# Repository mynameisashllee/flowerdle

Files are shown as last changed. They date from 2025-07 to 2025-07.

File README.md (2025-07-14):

# flowerdle
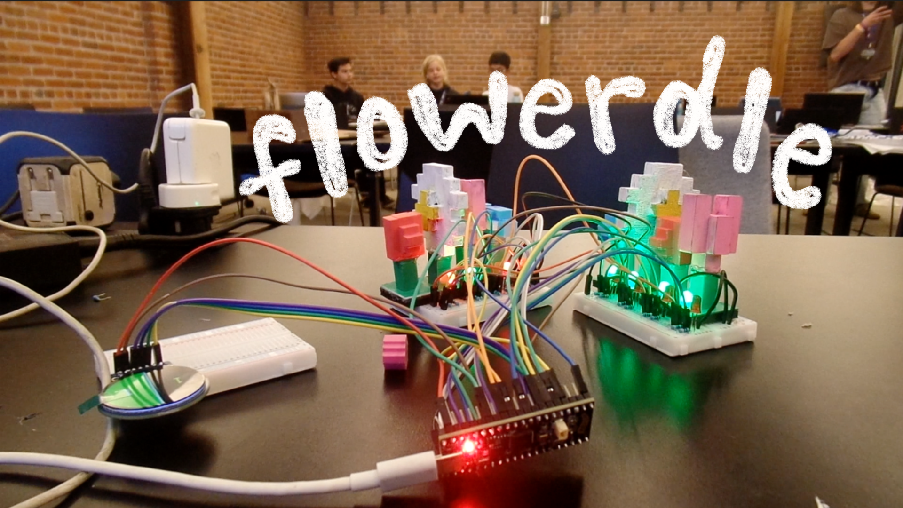
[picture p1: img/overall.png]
overall


## description
flowerdle is a real life two player wordle game - but instead of letters, there's minecraft flowers! and instead of one person, there's two! compete in a fierce race to guess the right flowers... or perish by pollen. just kidding.

## youtube demo
[link](https://youtu.be/ab2HIsHCvx8)

## how it works
there are four flowers - tulips (pink), poppies (red), oxeye daisies (white) and cornflowers (blue). each flower has a resistor of different resistance inside it to distinguish them. the resistors are held below each flower stem with a case, with pins poking out the bottom so you can plant them into the breadboard.
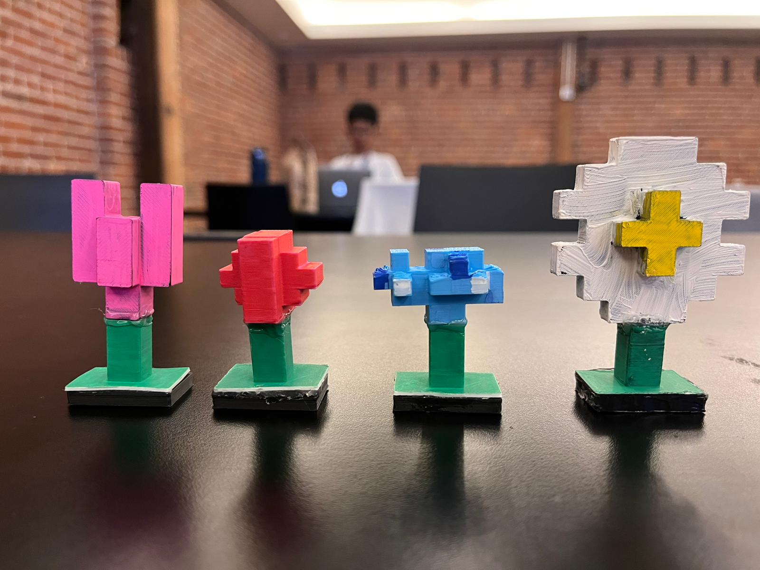
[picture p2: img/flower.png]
flower


at the start, the firmware generates a random four-colour code. the aim for both players is to guess the correct order of the colours in the least amount of tries.

there are 2 breadboards for players with spaces to put the flowers and leds (red and green).
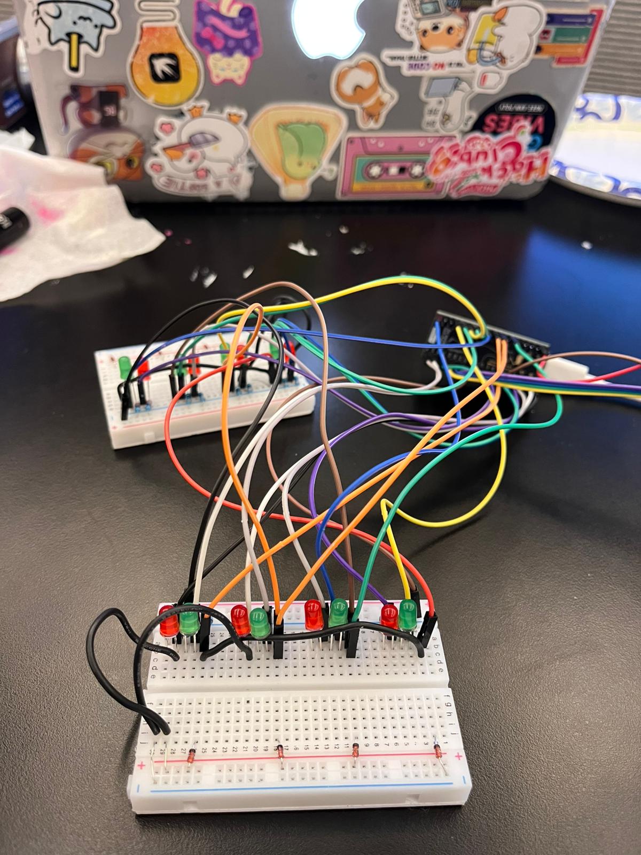
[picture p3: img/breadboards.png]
breadboards


and there's a breadboard for the oled display.
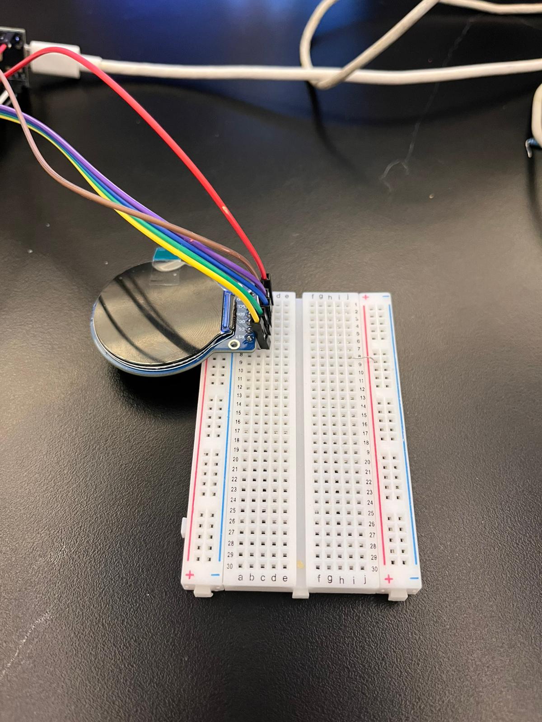
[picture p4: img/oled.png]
oled


the breadboard cases have unfortunately not been printed as of shipping, but hopefully will be before project demos! check out how they will look in the [cad files](src/cad/breadboardcase).

on each turn, you plug in all four flowers for your guess. then, the led lights up green or red based on whether the guess for that slot is correct or wrong, respectively.
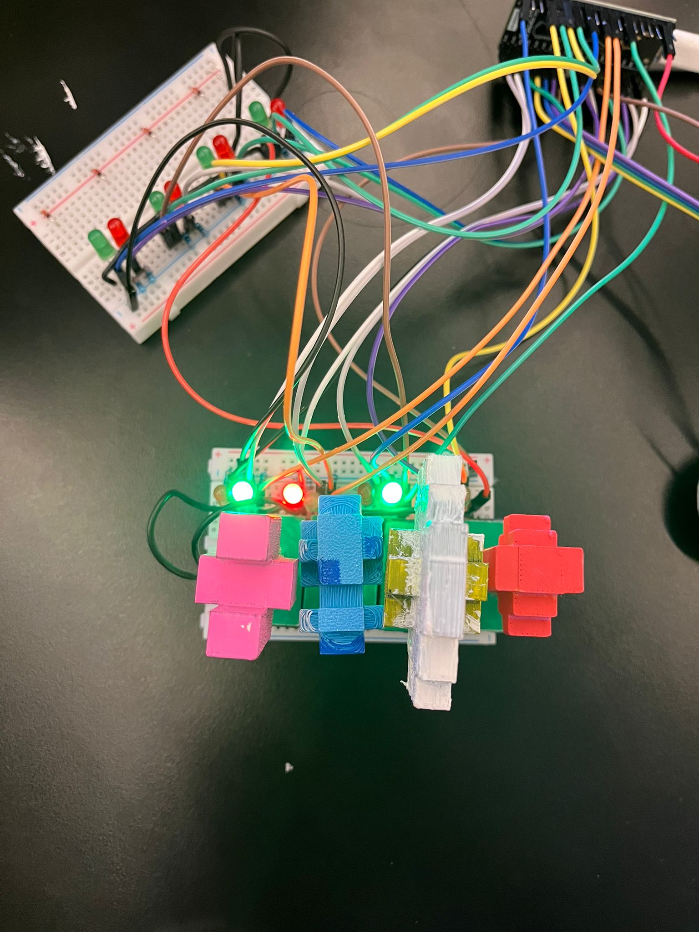
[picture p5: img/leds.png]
leds


once your turn is done, it increments the number of tries on the display. whoever gets the code correct first with the least number of tries wins! 
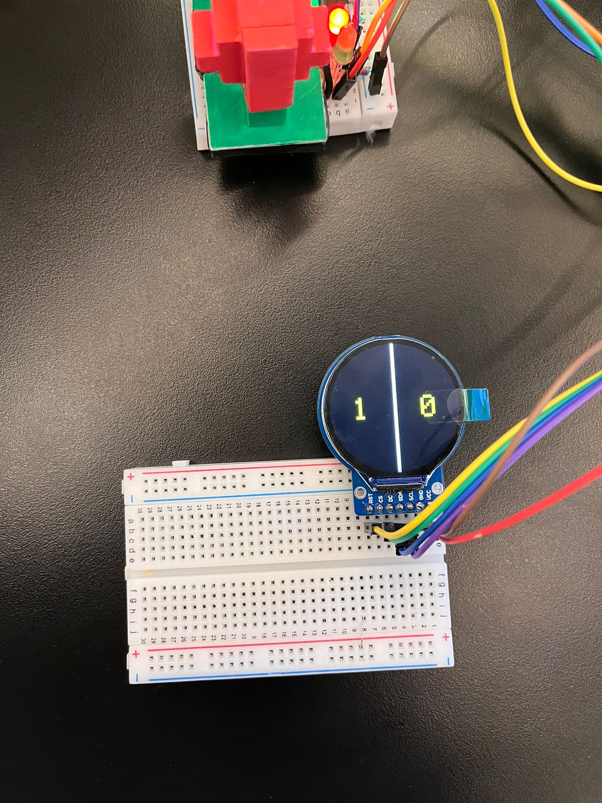
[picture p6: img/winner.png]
winner


## schematic
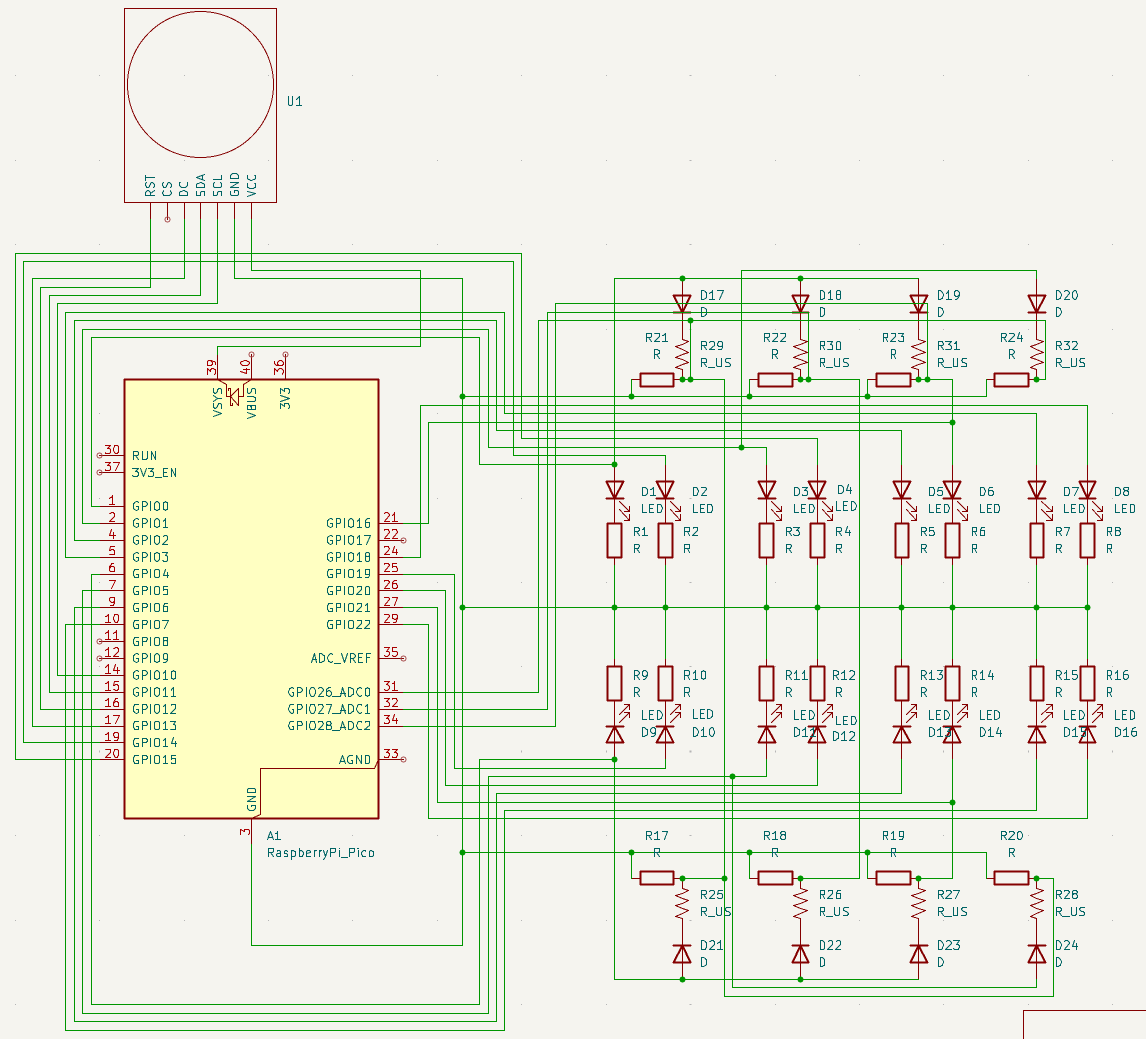
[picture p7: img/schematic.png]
schematic


## journal
take a look at our daily journals at [journals](journal) and our process pictures at [pictures](journal/pics.md) (featuring food pics!).

## building files
* 📂 src
    * [📂 cad](src/cad)
        * [📄 case cads](src/cad/breadboardcase)
        * [📄 flower cads](src/cad/flowers)
        * [📄 flower base cads](src/cad/structures)
    * [📂 firmware](src/firmware)
        * [📄 code.py](src/firmware/code.py)
    * [📂 schematic](src/schematic)
        * 📄 kicad files
    * [📄 bom](src/bom.md)

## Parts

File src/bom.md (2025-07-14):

# BOM
| Item | Amount |
| --- | --- |
| RP2040 | 1 |
| Breadboard | 3 |
| 390 resistor | 16 |
| 1.2k resistor | 8 |
| 2k resistor | 2 |
| 3.4k resistor | 2 |
| 4.2k resistor | 2 |
| 1.28" TFT LCD | 1 |
| LED (Red) | 8 |
| LED (Green) | 8 |
| Diode | 8 |
| Jumper wires (male - female) | 26 |
| Jumper wires (male - male) | 10 |
| Hot glue | lots |
| 3D Print Filament | lots |

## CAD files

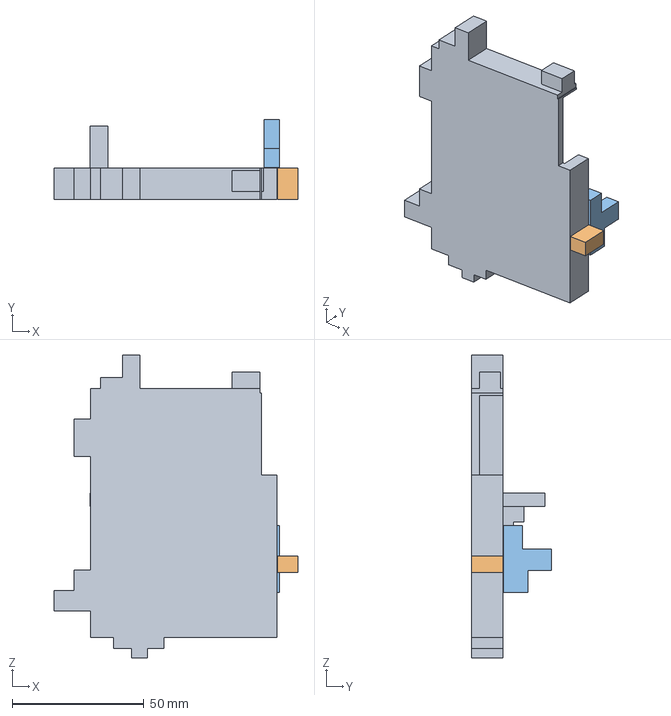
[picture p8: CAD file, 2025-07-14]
src/cad/breadboardcase/with_oled.step
92.5 x 30.5 x 115.0 mm

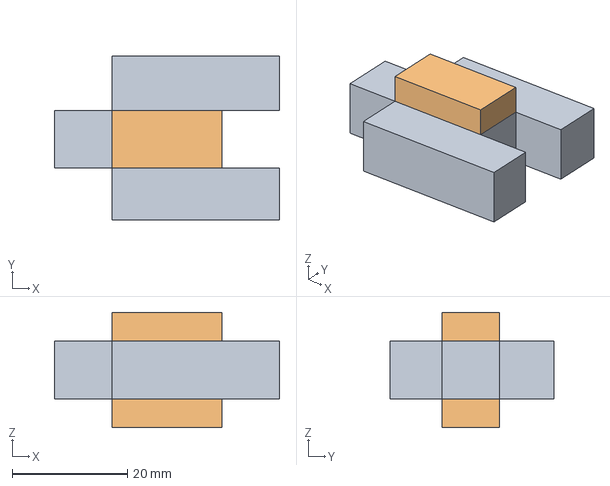
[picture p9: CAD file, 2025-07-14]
src/cad/flowers/pinkflower.step
39.0 x 28.4 x 20.0 mm

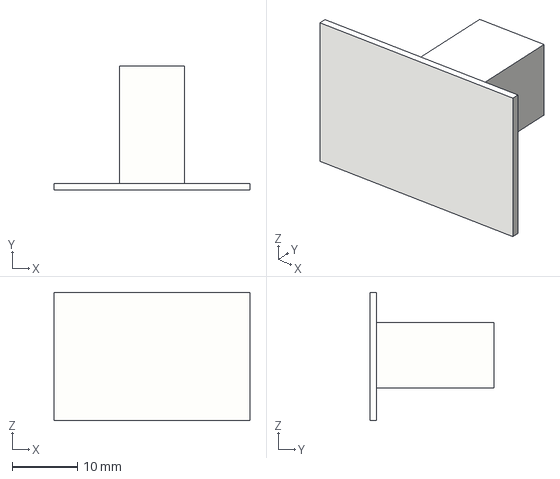
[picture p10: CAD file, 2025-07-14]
src/cad/structures/flowerstem.step
30.0 x 19.0 x 19.6 mm

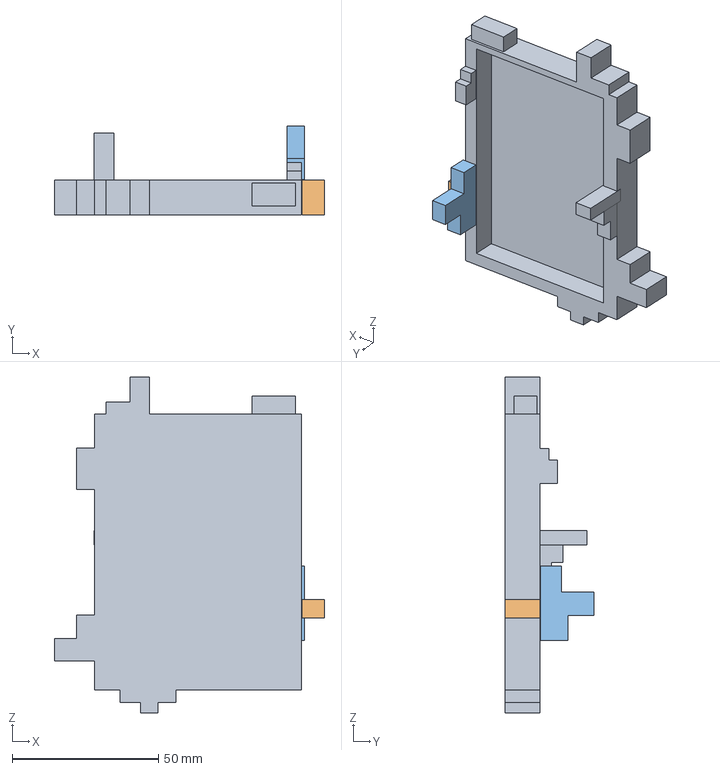
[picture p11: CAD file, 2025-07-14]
src/cad/breadboardcase/no_oled.step
92.5 x 30.5 x 115.0 mm

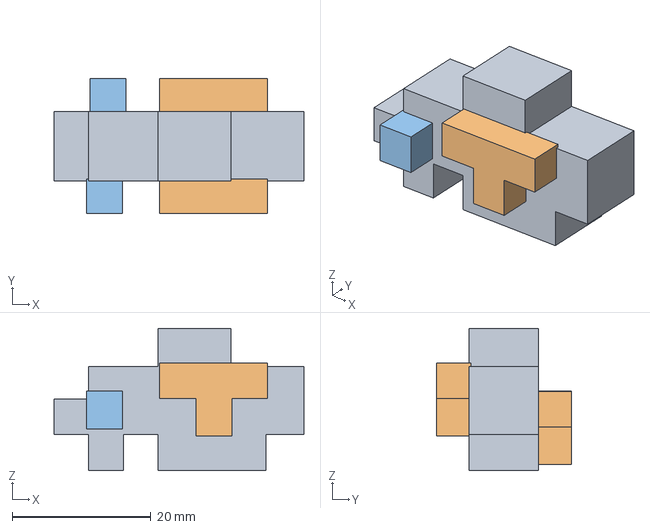
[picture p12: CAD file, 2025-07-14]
src/cad/flowers/blueflower.step
36.0 x 19.5 x 20.5 mm

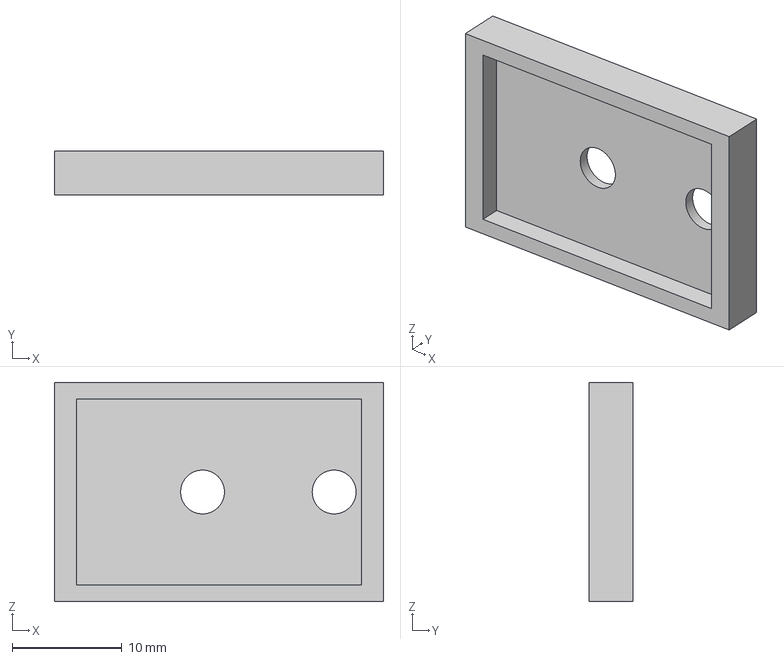
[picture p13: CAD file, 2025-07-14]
src/cad/structures/flowerbase.step
30.0 x 4.00 x 20.0 mm

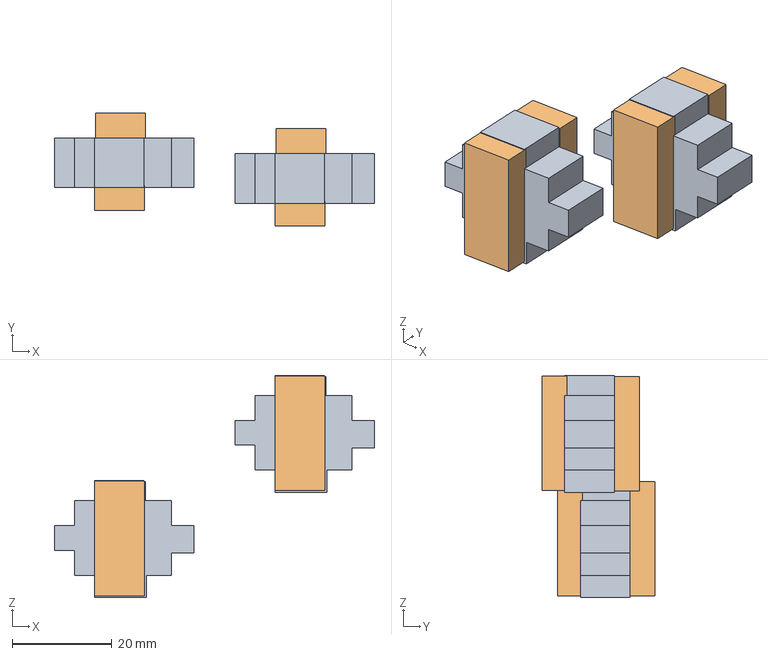
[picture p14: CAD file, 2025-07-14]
src/cad/flowers/redflower.step
64.2 x 22.7 x 44.6 mm

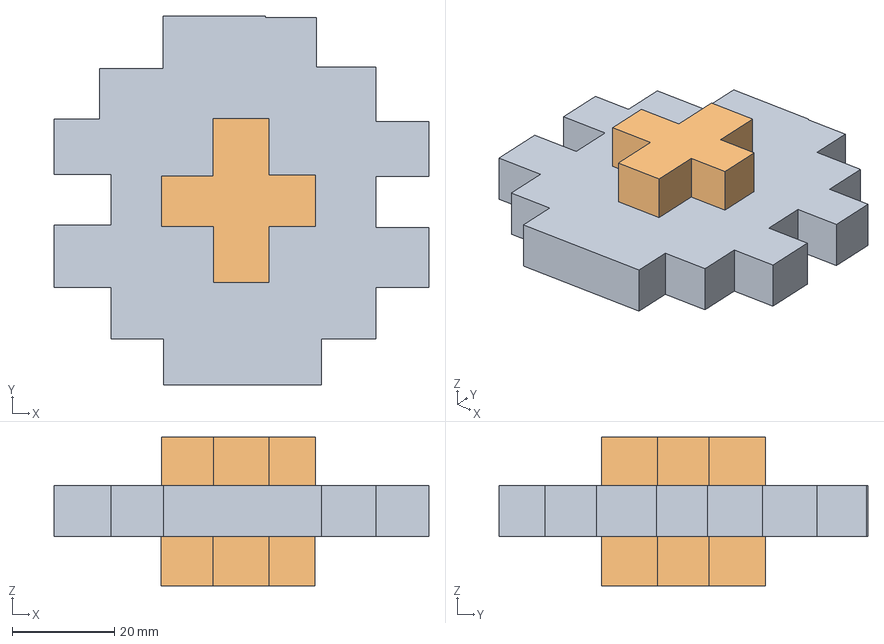
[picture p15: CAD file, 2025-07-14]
src/cad/flowers/whiteflower.step
73.2 x 72.1 x 29.0 mm

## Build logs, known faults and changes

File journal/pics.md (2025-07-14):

# digicam photos!
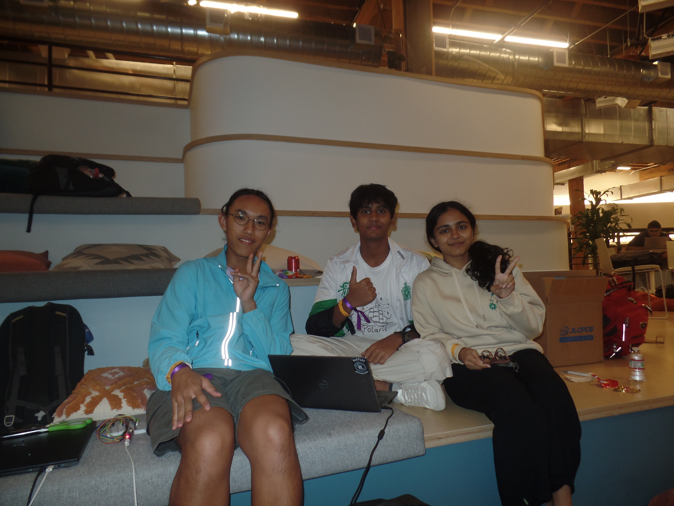
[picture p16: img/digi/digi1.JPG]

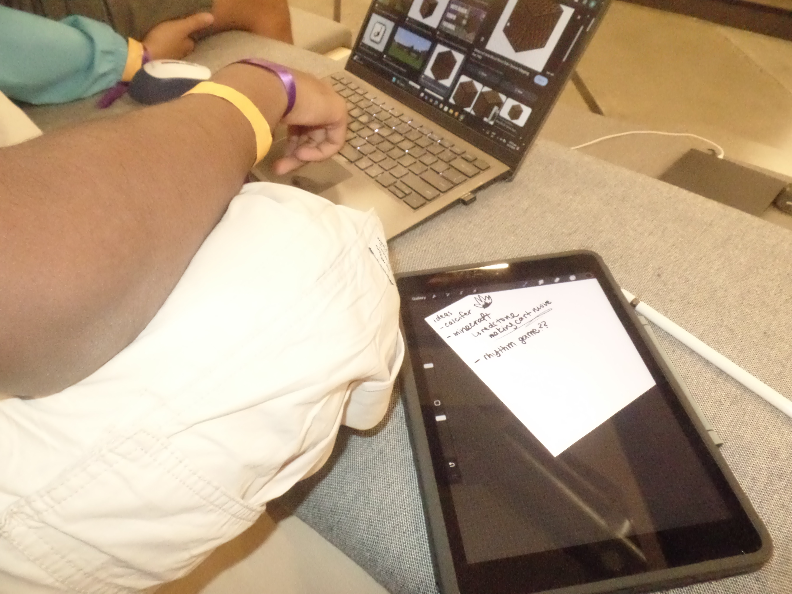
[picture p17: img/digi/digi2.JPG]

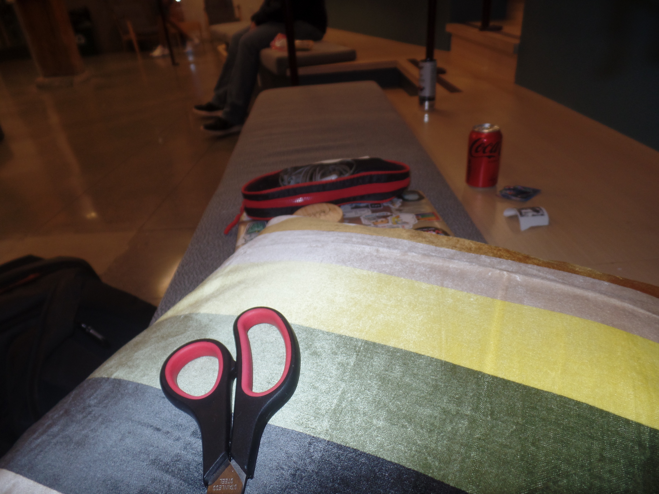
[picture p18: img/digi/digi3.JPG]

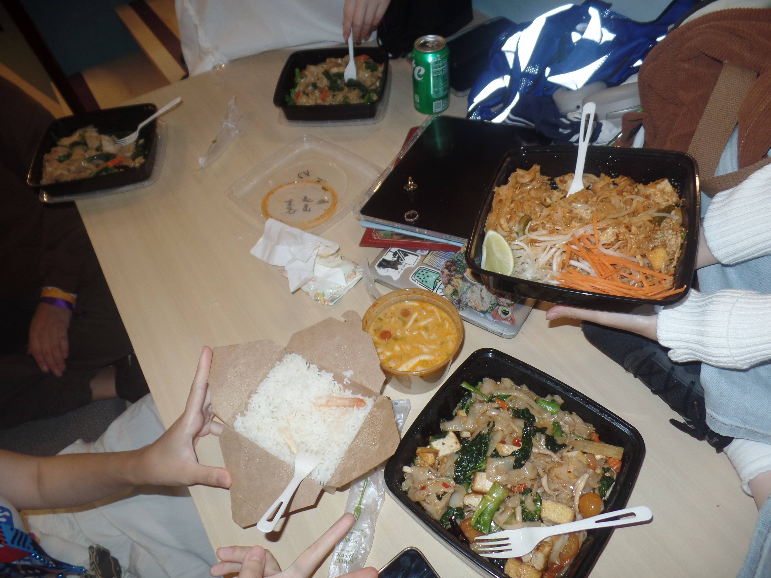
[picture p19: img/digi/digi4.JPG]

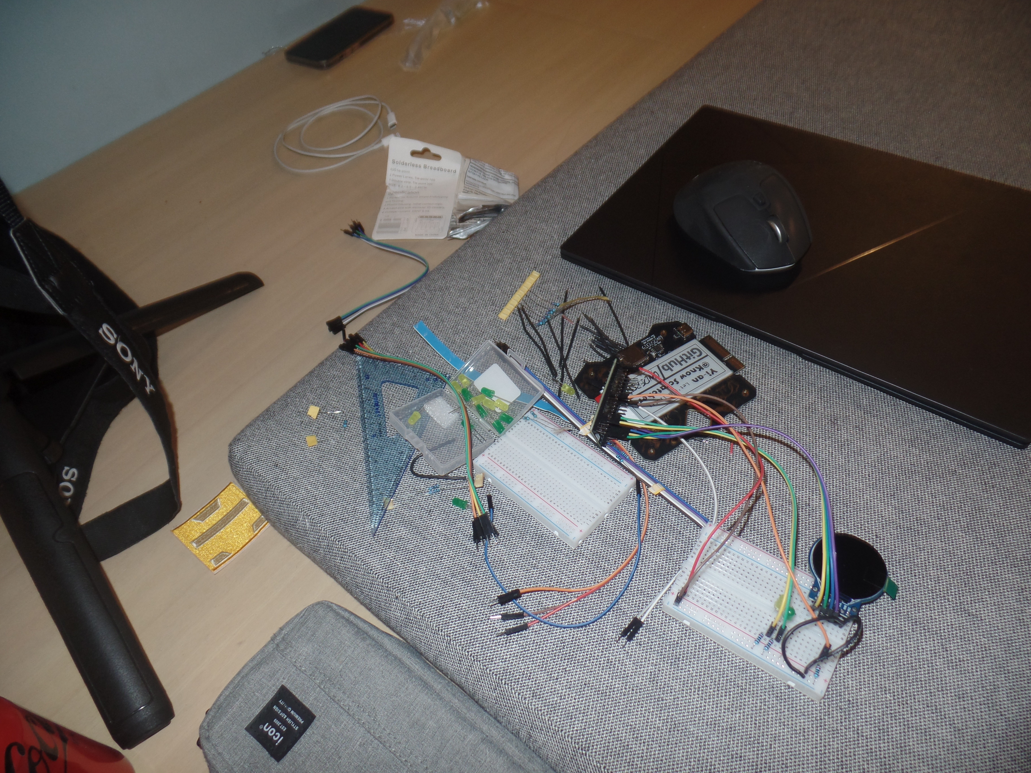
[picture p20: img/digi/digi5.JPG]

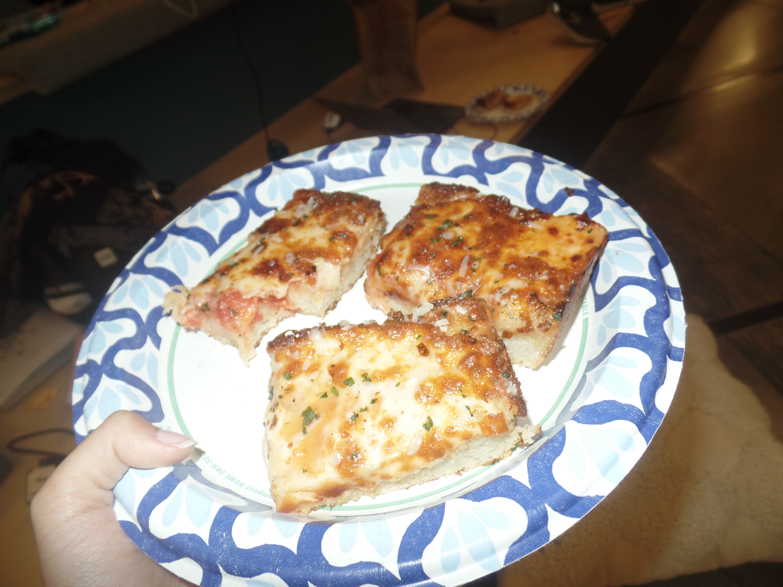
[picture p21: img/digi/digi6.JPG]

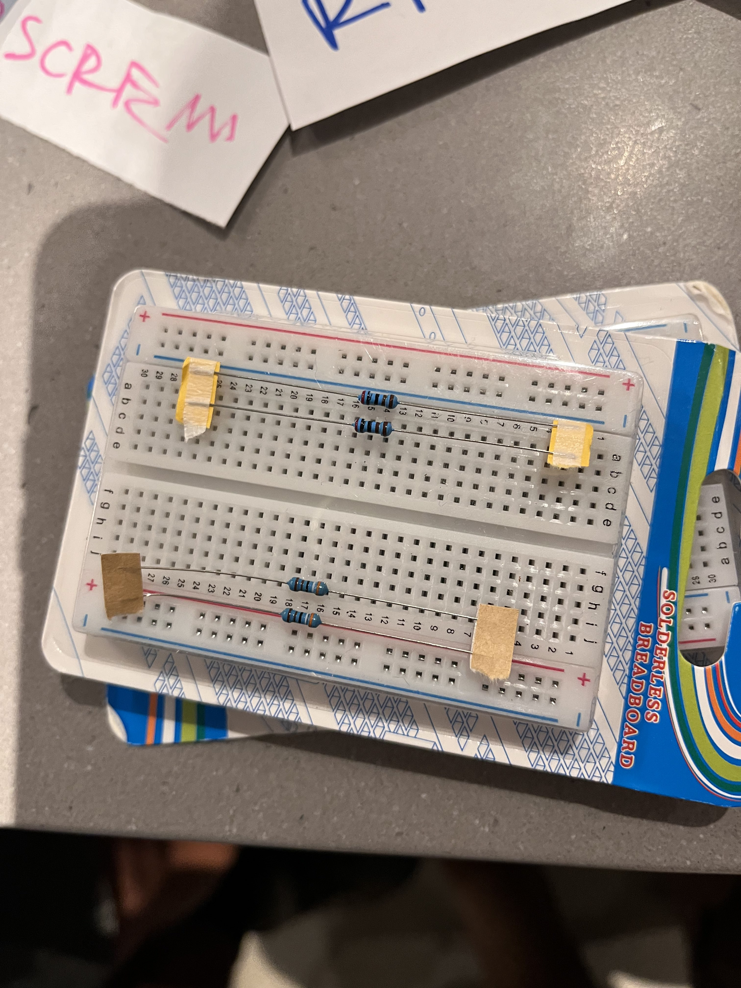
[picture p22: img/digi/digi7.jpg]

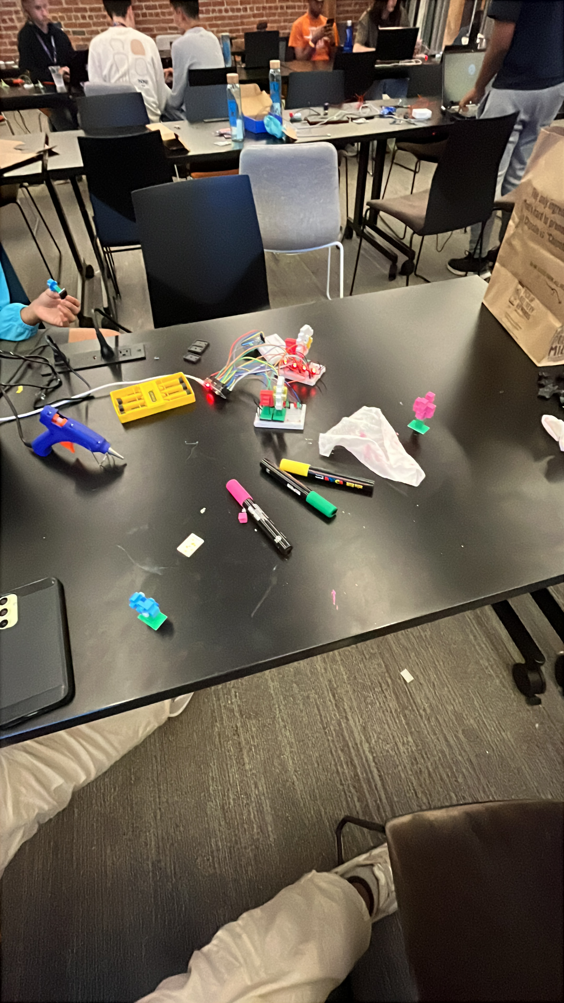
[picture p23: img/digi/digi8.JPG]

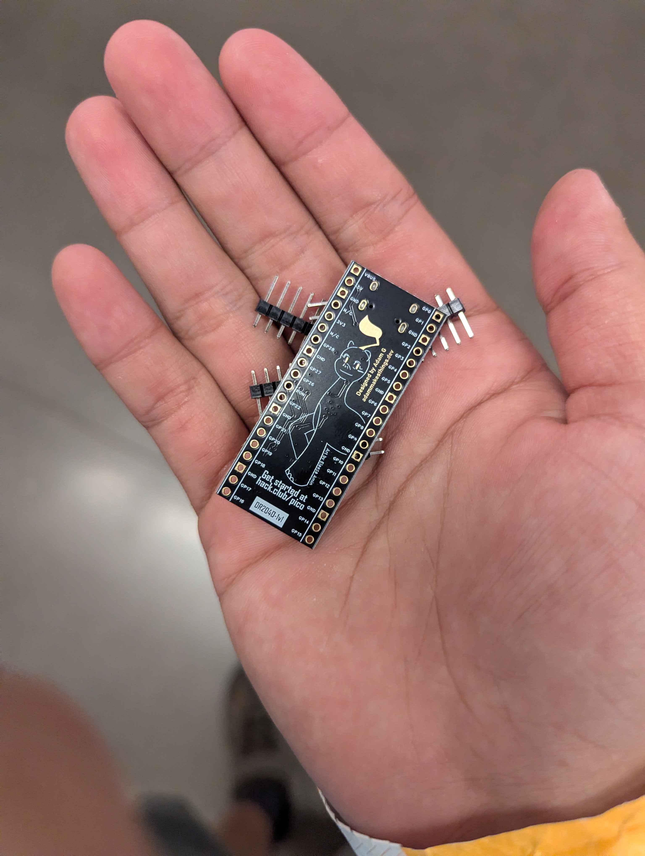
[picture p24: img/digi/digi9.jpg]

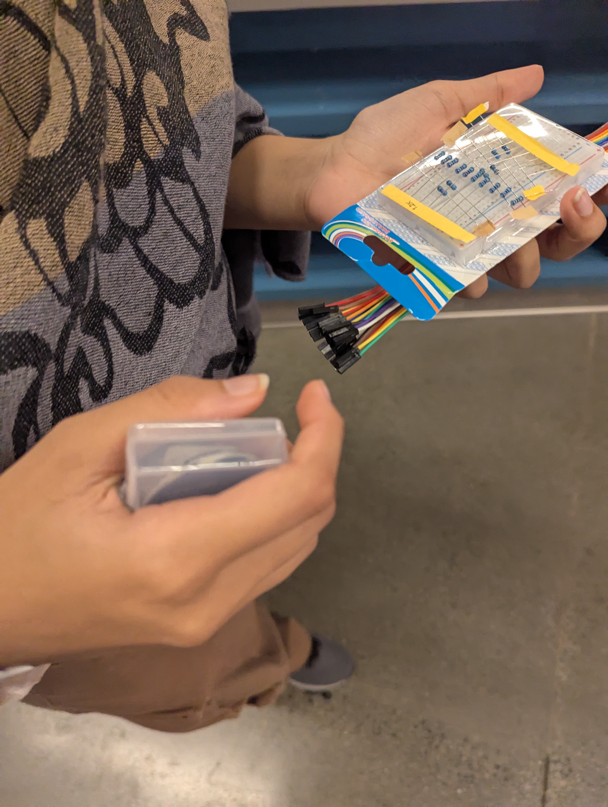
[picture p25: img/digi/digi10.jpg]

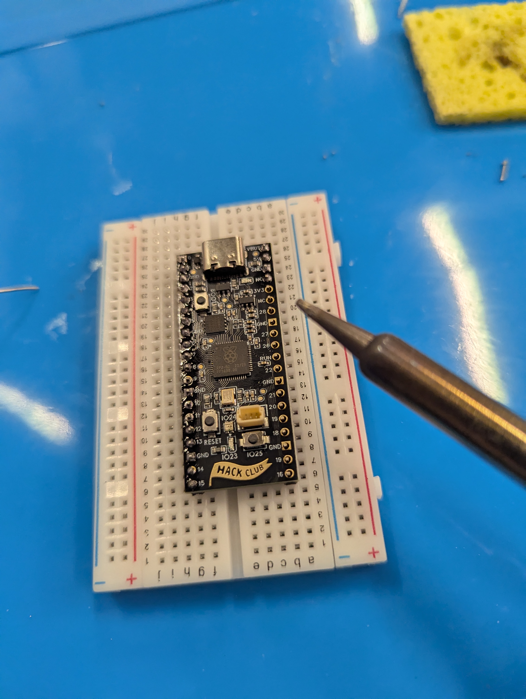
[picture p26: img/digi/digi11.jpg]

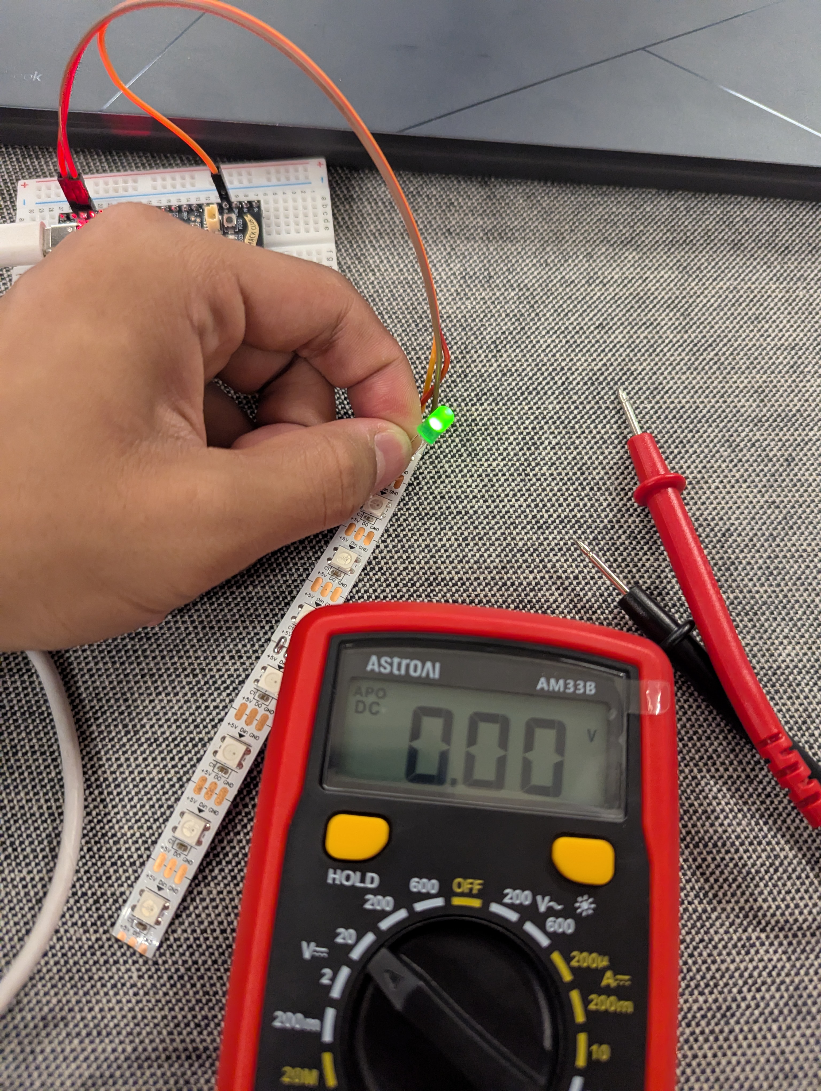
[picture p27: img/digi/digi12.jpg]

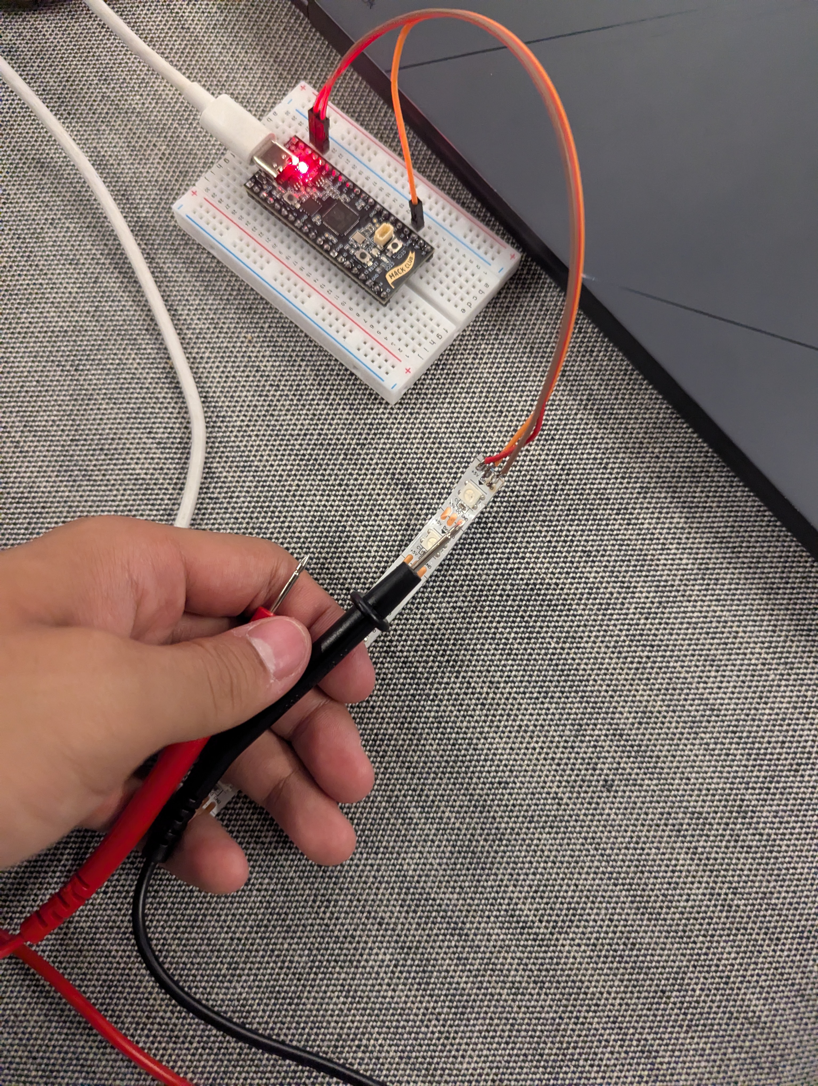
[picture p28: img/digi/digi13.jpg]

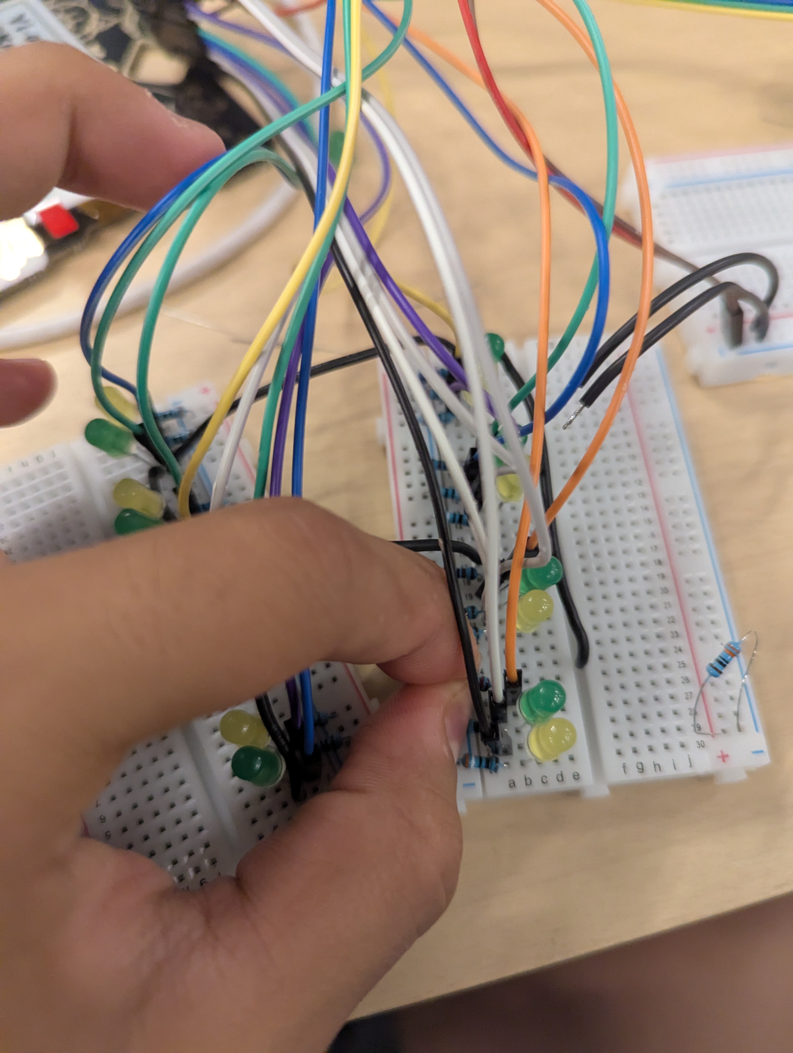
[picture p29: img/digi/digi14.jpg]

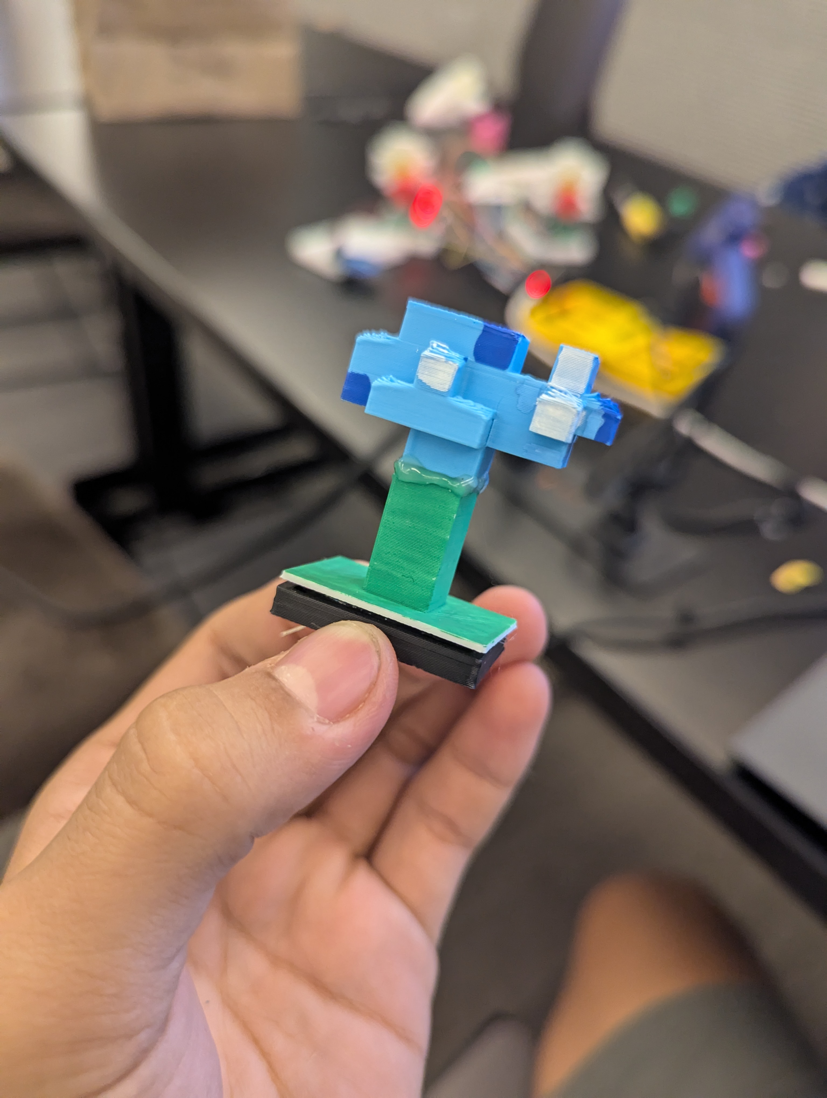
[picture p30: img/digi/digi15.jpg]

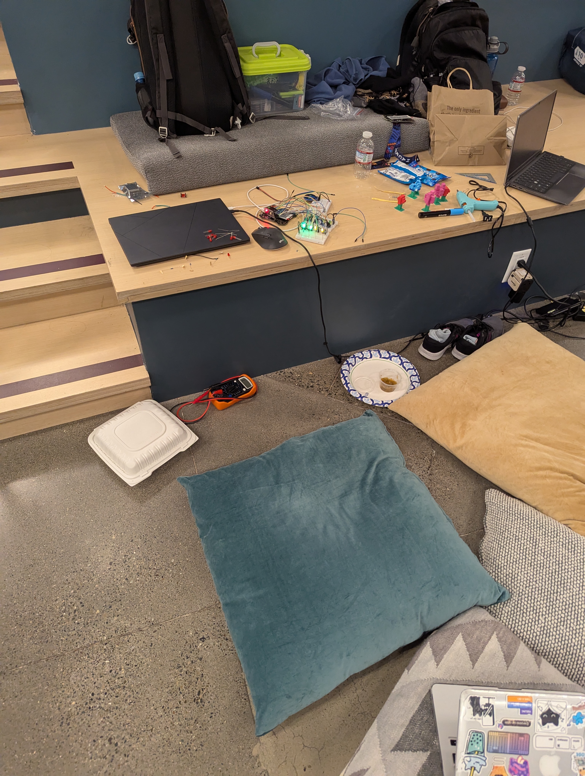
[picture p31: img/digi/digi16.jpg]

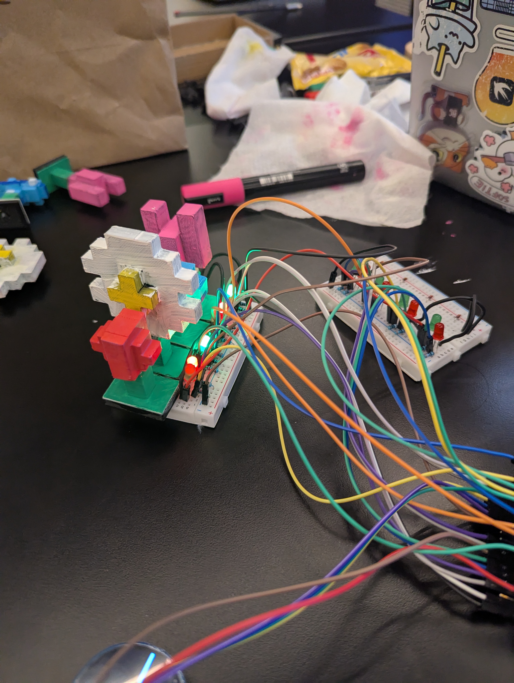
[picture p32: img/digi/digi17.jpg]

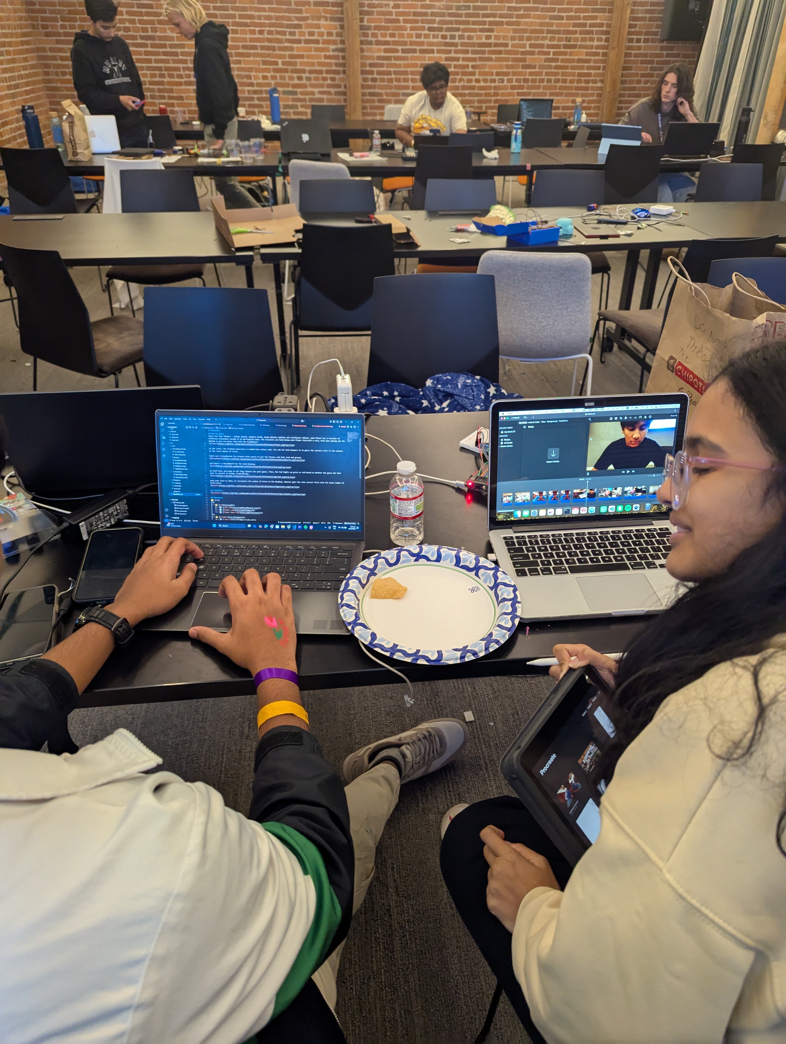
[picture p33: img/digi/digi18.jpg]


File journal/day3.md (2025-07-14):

# day 3 - 13 jul 
Its the last full day to finish our project(#crashingout). Okay but we're on track(kind of), except our 3d prints for two of our flowers aren't here yet. We finished working on the breadboard cases which are minecraft themed as well(grass blocks!!) The queue for the 3d printer is not looking good though but apparently we'll be able to start printing at 7pm and get it by 9!.

We also refined our firmware and got it fully functioning. 

We got our prints at around 9.30 but bad news!! Our prints are all in black(lowkey cooked given our game depends on having different coloured flowers). But the paint markers saved the day and we managed to get some white paint too and we repainted the flowers but we're yet to get out breadboard case which will apparently be ready before 8 am tomorrow.

Also WHY ARE 3D PRINT SUPPORTS SO HARD TO REMOVE?? (might've accidentally injured myself with the tweezers but we're balling!!)

We painted and assembled all our flowers and our electronics and fully tested things out at around 1.20 am after undernet and IT WORKS!!!

Now we just got to work on getting all our files ready to ship(which is all over the place ngl) and we're going to hope that tomorrow's breadboard cases come in time for us to assemble it. 

Might be a long night and we're all hiked up on so much caffiene but what's the fun in a hackathon if you're not up all night doing goofy things while speedrunning right? 

Thats it for day 3, and I should probably lock in now!

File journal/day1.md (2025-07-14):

## day 1 - 11 jul (fri)
for the first day, after settling in, we formed our teams and started brainstorming ideas (after some caffeine)

before settling on our final (floral!) idea, some of our scrapped ideas include:
- calcifer from howl's moving castle
- real life minecraft redstone minecart??
- mini rhythm game (like osu or taiko)

we figured that if we incorporated minecraft flowers into a codebreaker-style game, we retained a sense of whimsy while also making it more interactive. then, we got the idea to add two players for extra competition and fun (!!!)

basically, the firmware generates a random code of four colours which the players have to guess the sequence of by slotting minecraft flowers of the respective colours into four sockets. then, leds below the sockets tell you whether the flower is correct or wrong by lighting up red or green. to distinguish the different types of flowers, we are using resistors of varying resistance to complete the circuit. (we tried going through potential ideas for this like a photoresistor or distance sensors, but this was the most viable way)

by the time we figured out the circuit and went to collect our hardware, it was 2am. we discovered and soldered an orpheus pico and found this really fun round oled screen (thanks joe). we also got very many resistors which are really hard to distinguish in low light and while sleep deprived.

at about 2.40am, we tried to clear up the mess and created the repo. sadly, we realised that we had forgotten to get the leds and resistors and include them in the wiring ): job for tomorrow. goodnight!

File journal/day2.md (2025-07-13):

# day 2 - 12 jul (sat)
today, we woke up super early and split up tasks.

we did some cad and 3d printed the flowers! we decided on four colours according to the filament - dandelion for yellow, tulip for pink, cornflower for blue and rose for red. For the tulips, we printed out individual blocks and glued them together because it didnt need too many but for the rest we just patterned them in cad instead of assembling it to save on time. 
the bottom plate needed some adjustment because the resistor holes didn't print right, and the size was kind of off. so i guess that's a problem for tomorrow. 
Had 2 project demos today which went quite well, and we went through our 3d designs that were printed out as well as our firmware.
Turns out the other two were printed in the wrong colour and our adjusted bottom plate is yet to be printed so those two are a problem for tomorrow i guess
Right now we're relying on paint markers to fix the colour problems in case too many people need the 3d printers tomorrow
and thats it for the night. goodnight!

or probably not so fast, cus I just stayed up and try to get the firmware done.

It was a pretty serious problem: the pins are not enough.
So I go google for some details and found something worse: not only the GPIO pin are not enough, bout we only have 3 analog pins to read 4 analog data.
I searched online to see if I can find any solution. I also talked to Gemini. But after all, I decide I .have to share the pins.

This is basically how it's going to work.
First, I can use a main GPIO pin to provide power for the sensor, and then just read the values and cut it off and switch to the secondary GPIO pin and read the remaining value, and finally switch back to the original state.

I worked like till 4 am. so hope I can still lock in tomorrow. (PS I'm having too much caffeine I'm just want to sleep now.)

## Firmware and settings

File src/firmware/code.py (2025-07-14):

import board
import digitalio
import analogio
import time
import os
import random
import math
import busio
import terminalio
import displayio
from adafruit_display_text import label
import gc9a01 # type: ignore
from vectorio import Rectangle

# Release any resources currently in use for the displays
displayio.release_displays()

# Raspberry Pi Pico pinout, one possibility, at "southwest" of board
tft_clk = board.GP10 # must be a SPI CLK
tft_mosi= board.GP11 # must be a SPI TX
tft_rst = board.GP12
tft_dc  = board.GP13
tft_cs  = None
tft_bl  = None
spi = busio.SPI(clock=tft_clk, MOSI=tft_mosi)

display_bus = displayio.FourWire(spi, command=tft_dc, chip_select=tft_cs, reset=tft_rst) # type: ignore
display = gc9a01.GC9A01(display_bus, width=240, height=240, backlight_pin=tft_bl)

# Make the main display context
main = displayio.Group()
display.root_group = main



# Draw a text label
palette = displayio.Palette(1)
palette[0] = 0xffffff
bar_group = displayio.Group(scale=2)
bar = Rectangle(pixel_shader=palette, x=60, y=0, width=5, height=240)
bar_group.append(bar)
main.append(bar_group)
p1_status = displayio.Group(scale=2)
p2_status = displayio.Group(scale=2)
palette_win = displayio.Palette(1)
palette_win[0] = 0x00ff00
palette_lose = displayio.Palette(1)
palette_lose[0] = 0xff0000
p1_color = Rectangle(pixel_shader=palette_win, x=0, y=0, width=120, height=240)
p2_color = Rectangle(pixel_shader=palette_win, x=60, y=0, width=120, height=240)
p1_status.append(p1_color)
p2_status.append(p2_color)

p1_count, p2_count = 0, 0
p1_text = str(p1_count)
p1_text_area = label.Label(terminalio.FONT, text=p1_text, color=0xFFFF00,
                        anchor_point=(3.5,3.5), anchored_position=(30,60))
p1_text_group = displayio.Group(scale=5)
p1_text_group.append(p1_text_area) 
main.append(p1_text_group)

p2_text = str(p2_count)
p2_text_area = label.Label(terminalio.FONT, text=p2_text, color=0xFFFF00,
                        anchor_point=(3.5,3.5), anchored_position=(55,60))
p2_text_group = displayio.Group(scale=5)
p2_text_group.append(p2_text_area) 
main.append(p2_text_group)

wrong_pins = [board.GP0, board.GP1, board.GP2, board.GP3, board.GP4, board.GP5, board.GP6, board.GP7]
right_pins = [board.GP14, board.GP15, board.GP16, board.GP18, board.GP19, board.GP20, board.GP21, board.GP22]
analog_pins = [board.GP26, board.GP27, board.GP28]

wrongs: list[digitalio.DigitalInOut] = []
rights: list[digitalio.DigitalInOut] = []
analog: list[analogio.AnalogIn] = []
for i in wrong_pins:
    wrongs.append(digitalio.DigitalInOut(i))
    wrongs[-1].direction = digitalio.Direction.OUTPUT
for i in right_pins:
    rights.append(digitalio.DigitalInOut(i))
    rights[-1].direction = digitalio.Direction.OUTPUT
for i in analog_pins:
    analog.append(analogio.AnalogIn(i))

# mp = {
#     48: 0,
#     47: 0,
#     46: 0,
#     36: 1,
#     35: 1,
#     34: 1,
#     23: 2,
#     22: 2,
#     21: 2,
#     13: 3,
#     12: 3,
#     11: 3
# }
# mp = {
#     32: 0,
#     31: 0,
#     30: 0,
#     24: 1,
#     23: 1,
#     22: 1,
#     16: 2,
#     15: 2,
#     14: 2,
#     9: 3,
#     8: 3,
#     7: 3
# }
mp = {
    31: 0,
    30: 0,
    29: 0, 
    20: 1,
    19: 1,
    18: 1,
    13: 2,
    12: 2,
    11: 2,
    7: 3,
    6: 3,
    5: 3
}
# v4
# 820 = 30***
# 2k   = 19***
# 3.4k = 12***
# 4.2k = 6***

def read(sw1:  digitalio.DigitalInOut, sw2:  digitalio.DigitalInOut, sw3:  digitalio.DigitalInOut, sw4:  digitalio.DigitalInOut):
    tmp1, tmp2, tmp3, tmp4 = sw1.value, sw2.value, sw3.value, sw4.value
    p1, p2 = [], []
    sw1.value, sw2.value, sw3.value, sw4.value = True, False, False, False # p1 main
    p1.append(analog[0].value)
    p1.append(analog[1].value)
    p1.append(analog[2].value)
    sw1.value, sw2.value, sw3.value, sw4.value = False, True, False, False # p1 sub
    p1.append(analog[0].value)
    sw1.value, sw2.value, sw3.value, sw4.value = False, False, True, False # p2 main
    p2.append(analog[0].value)
    p2.append(analog[1].value)
    p2.append(analog[2].value)
    sw1.value, sw2.value, sw3.value, sw4.value = False, False, False, True # p2 sub
    p2.append(analog[0].value)
    sw1.value, sw2.value, sw3.value, sw4.value = tmp1, tmp2, tmp3, tmp4
    return p1, p2

    

nums = [0, 1, 2, 3]
ans = []
seed_bytes = os.urandom(4)
seed_int = int.from_bytes(seed_bytes, 'big')
random.seed(seed_int)
for i in range(4):
    index = random.randint(0, len(nums) - 1)
    ans.append(nums[i % len(nums)])
    nums.pop(i % len(nums))
print(ans)

p1_lock, p2_lock = False, False
while True:
    p1, p2 = read(wrongs[0], wrongs[1], wrongs[4], wrongs[5])
    print(p1, p2)
    if all([x // 1000 > 0 for x in p1]):
        if not p1_lock and p1_count >= 0:
            p1_lock = True
            p1_count += 1
            p1_text_area.text = str(p1_count)
            for i in range(4):
                wrongs[i].value = not(mp.get(p1[i] // 1000, ans[i]) == ans[i])
                rights[i].value = mp.get(p1[i] // 1000, -1) == ans[i]
            if all(mp.get(p1[i] // 1000, -1) == ans[i] for i in range(4)):
                main.insert(0, p1_status)
                p1_text_area.color = 0xffffff
                p1_count = -1
    else: #if all([x // 1000 < 0 for x in p1]) and p1_lock:
        for i in range(4):
            wrongs[i].value = False
            rights[i].value = False
        p1_lock = False

    if all([x // 1000 > 0 for x in p2]):
        if not p2_lock and p2_count >= 0:
            p2_lock = True
            p2_count += 1
            p2_text_area.text = str(p2_count)
            for i in range(4):
                wrongs[i + 4].value = not(mp.get(p2[i] // 1000, ans[i]) == ans[i])
                rights[i + 4].value = mp.get(p2[i] // 1000, -1) == ans[i]
            if all(mp.get(p2[i] // 1000, -1) == ans[i]for i in range(4)):
                main.insert(0, p2_status)
                p2_text_area.color = 0xffffff
                p2_count = -1
    else: #if all([x // 1000 < 0 for x in p2]) and p2_lock:
        for i in range(4):
            wrongs[i + 4].value = False
            rights[i + 4].value = False
        p2_lock = False
    time.sleep(0.5)
# v1
# 1.2k = 47***
# 2k   = 35***
# 3.4k = 22***
# 4.2k = 12***

# v2
# 1.2k = 31***
# 2k   = 23***
# 3.4k = 15***
# 4.2k = 8***

# v3
# 1.2k = 25***
# 2k   = 19***
# 3.4k = 12***
# 4.2k = 6***

# v4
# 820 = 30***
# 2k   = 19***
# 3.4k = 12***
# 4.2k = 6***

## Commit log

2025-07-12 update BOM
2025-07-14 update BOM, update firmware
2025-07-14 organised and edited readme
    [blueflower.step, flowerbase.step, flowerstem.step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]
2025-07-14 update sch
    [flowerdle.kicad_sch]
2025-07-14 update pics n links
    [no_oled.step, with_oled.step]
